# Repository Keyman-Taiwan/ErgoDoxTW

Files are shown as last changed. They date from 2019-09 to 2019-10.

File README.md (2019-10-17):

# ErgoDoxTW
Change was made based on [ErgoDone v1.5](https://github.com/ktec-hq/ErgoDone/commit/091d1d12327a9dc95b3b4be09c8e6d85ce0d4d30)  

## PCB Preview in KiCad
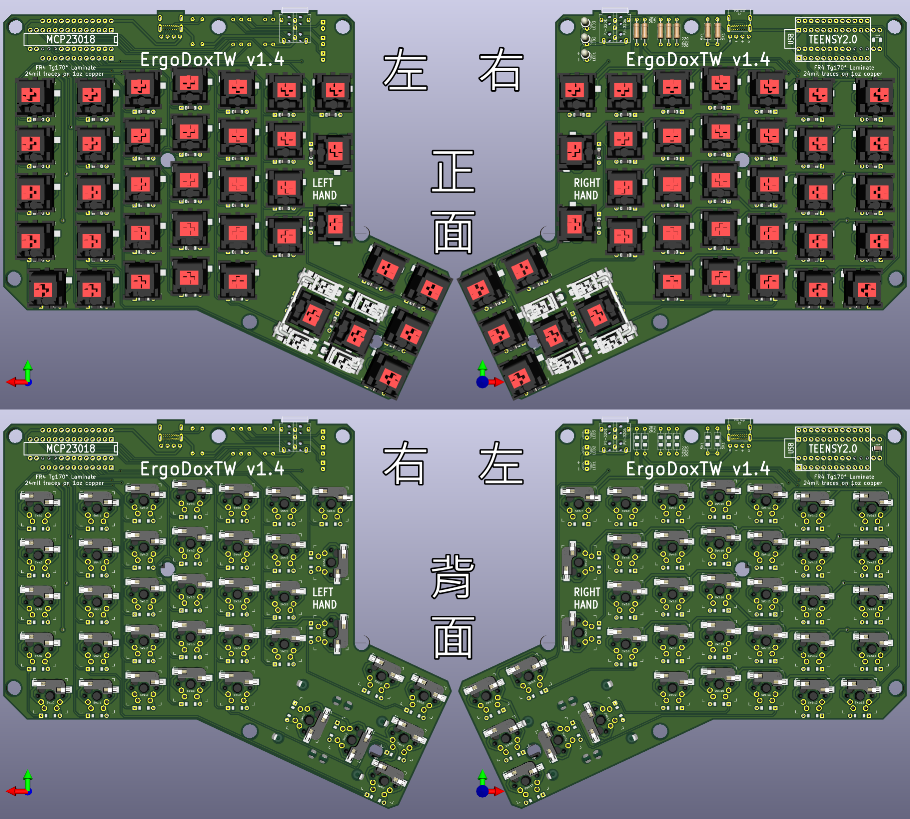
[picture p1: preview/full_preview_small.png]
pcb preview

You can find a larger image in the preview folder.

`IMPORTANT`: v1.4 has been validated.

## Difference/Improvement with ErgoDone
1. Rollback to use Teensy 2.0 for main controller (same as ErgoDox)
2. Rollback to use MCP23018 for IO expander (same as ErgoDox)
3. USB Type-C connector (only support USB 2.0 due to Teensy 2.0)
4. Support to use Kailh / Gateron hot plug socket
5. Support to use SMD 1206 component for Resistor and Capacitor
6. Change TRRS socket to PJ-320A and PJ-320E, which is more easy to find and cheapper. (please check folder ref_data/3.5mm
)
7. **`ONLY`** support 76 keys due to component change and pcb layout change.

## Branch Description
* master & USB_C_DIP_RightHand: Teensy IC on Right hand (Compatible with ErgoDox-EZ Configurator)
* USB_C_DIP: Teensy IC on Left hand

## Software Requirement
* Kicad 5.1.4

## KiCad library used by ErgoDoxTW
* [ai03-2725/Type-C Connecter](https://github.com/ai03-2725/Type-C.pretty): HRO-TYPE-C-31-M-12
* [daprice/keyswitches](https://github.com/daprice/keyswitches.pretty): Kailh hotplug socket
* Some components in ErgoDone's library
* Some components in ErgoDox's library

## KiCad Plugin used by ErgoDoxTW
* [NilujePerchut/kicad_scripts](https://github.com/NilujePerchut/kicad_scripts): teardrop pluging

## 3D model for preview
* [Kailh Hotplug Socket](https://github.com/qmk/qmk_hardware/tree/master/components): from qmk @ github
* [Cherry MX switch](https://github.com/ConstantinoSchillebeeckx/cherry-mx-switch): from ConstantinoSchillebeeckx @ github
* [Cherry MX Stabilizer](https://grabcad.com/library/cherry-mx-stabilizer-mx-1): from GrabCad
* SMD Diode / Resistor / LED are built-in model in KiCad

## BOM List
| Item | Amount | Comment |
|:---:|:---:|:---:|
| PCB boards | 2 | One for each hand |
| Teensy 2.0 | 1 | Maion controller |
| MCP23018 | 1 | I/O expander, Please choose DIP type |
| 2.54mm Header Pins | 24 | Unless pre-installed on the teensy board |
| Key switches | 76 | Compatible with Cherry MX is fine. |
| Key Switch Hotplug Socket | 76 | Kailh or Gateron. This is Optional |
| Key Caps | 76 | |
| 1N4148 diodes | 76 | SOD-123 package (SMD Type) or DO-35 (0.3” pitch) (Through-Hole Type) |
| 3mm T1 LED | 3 | |
| 220 Ω Resistor | 3 | Through-Hole Type Or 1206 SMD type (Red, Red, Brown) |
| 2.2k Ω Resistor | 2 | Through-Hole Type Or 1206 SMD type (Red, Red, Red) |
| 5.1k Ω Resistor | 2 | Through-Hole Type Or 1206 SMD type (Green, Brown, Red) |
| 0.1μ F Capacitor | 1 | ceramic capacitor (marked “104” for 10*104 picofarad, or 100nF), also supported 1206 smd type. Not strictly necessary but suggested. |
| USB Type C connector | 1 | 林躍電子 UB228-F16S4BR-A_DIP Or 浙富電子 16P 雙排 DIP |
| USB mini B plug with short cable | 1 | Such as H2955. Use for connect type c connector and teensy board |
| USB Type C Cable | 1 | A male to male cable, for connect keyboard to PC. (A to C) or (C to C) depend on your device. |
| 3.5mm TRRS socket | 2 | PJ-320A or PJ-320E |
| 3.5mm TRRS Cable | 1 | A male to male cable, for connect two pcbs. |
| ErgoDoxTW Keyboard case | 1 | Acrylic Case |

# Lisence
GPL v3

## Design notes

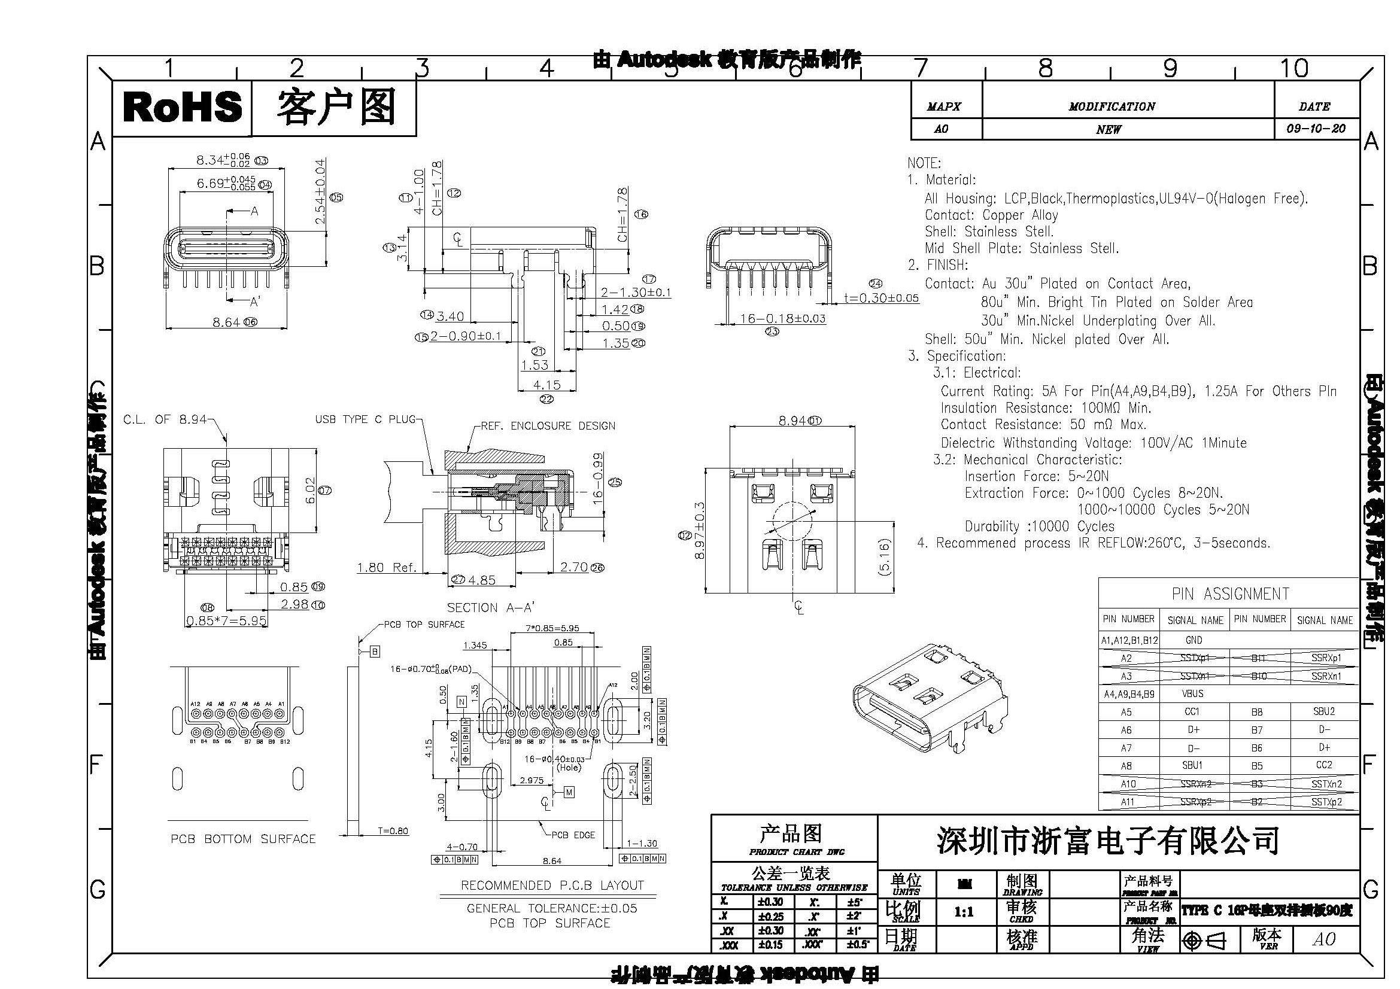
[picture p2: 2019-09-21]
ref_data/type_c/浙富电子_16P_雙排_DIP.jpg

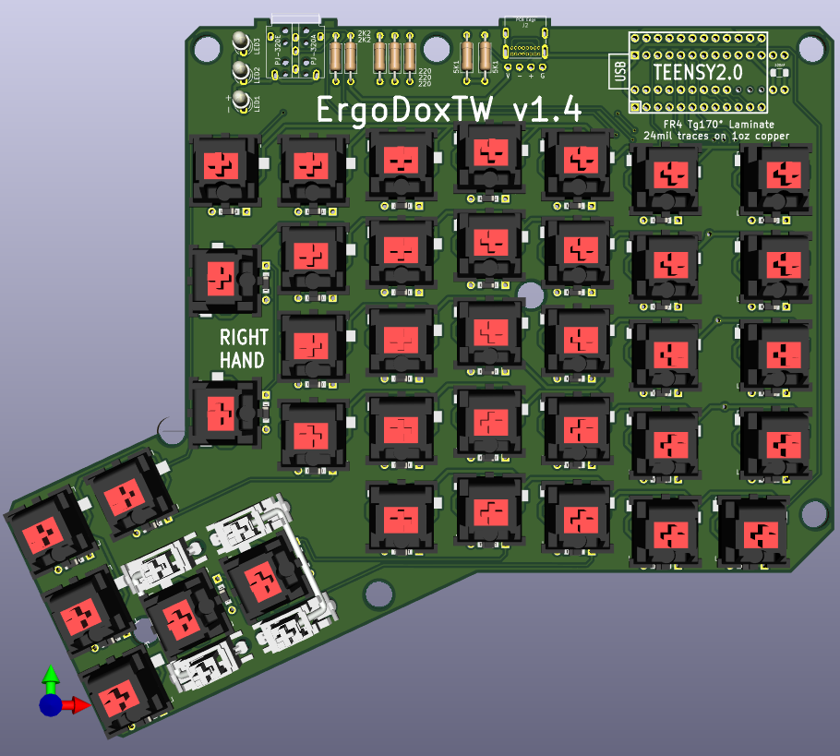
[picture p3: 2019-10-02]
preview/v1.4_RightHand_Top.png

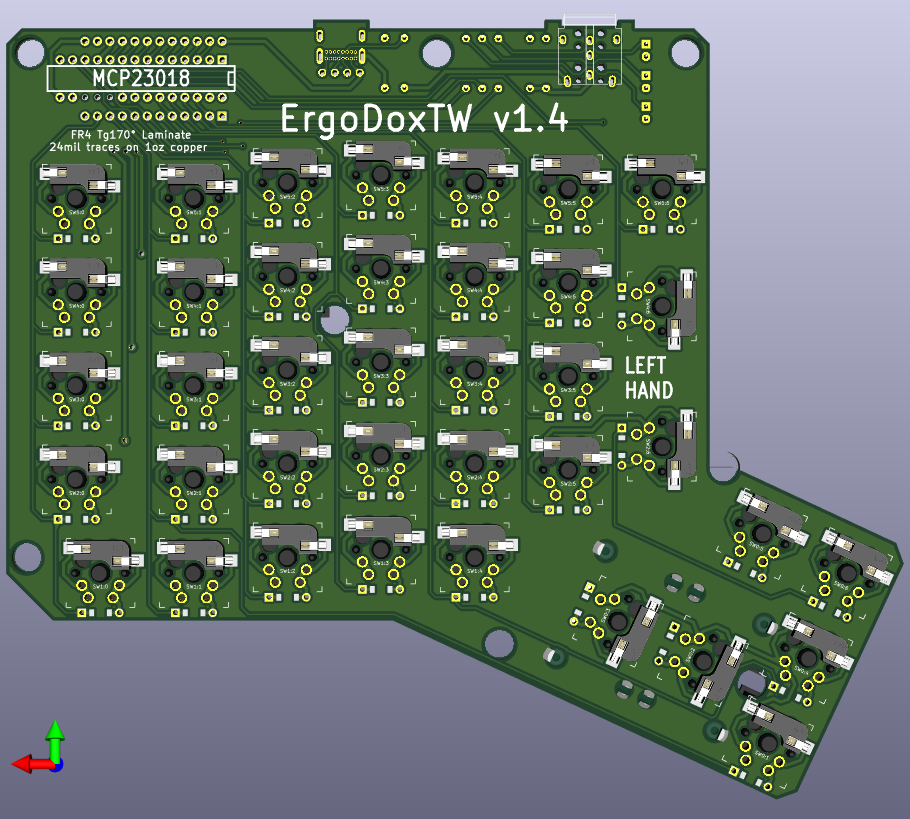
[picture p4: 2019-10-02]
preview/v1.4_RightHand_Bottom.png

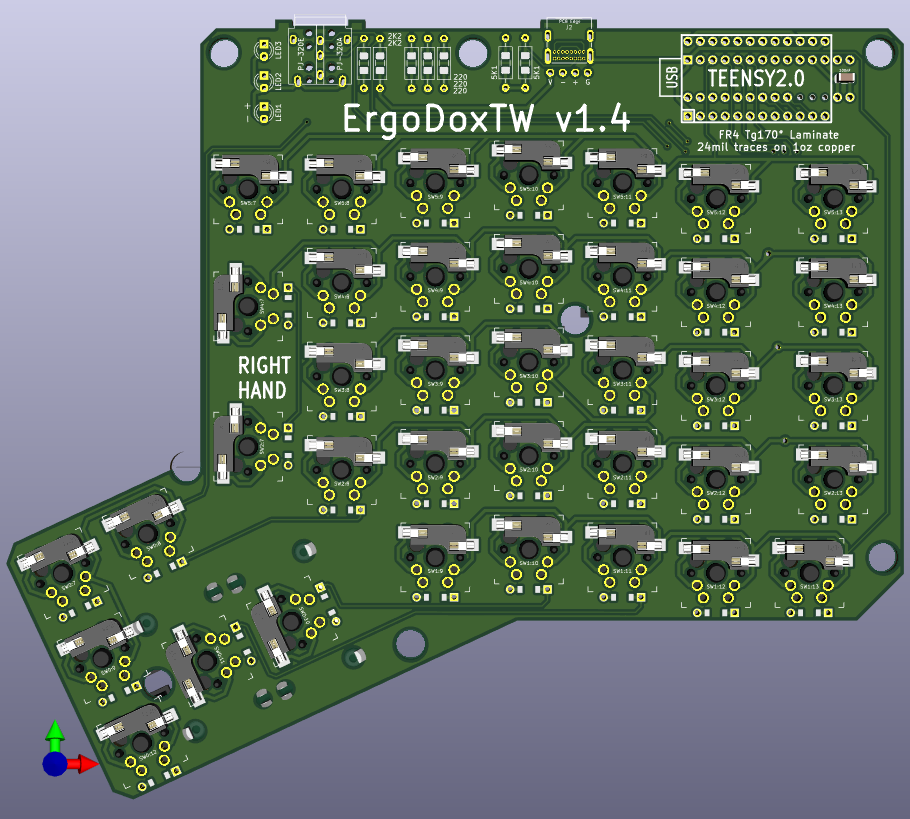
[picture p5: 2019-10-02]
preview/v1.4_LeftHand_Bottom.png

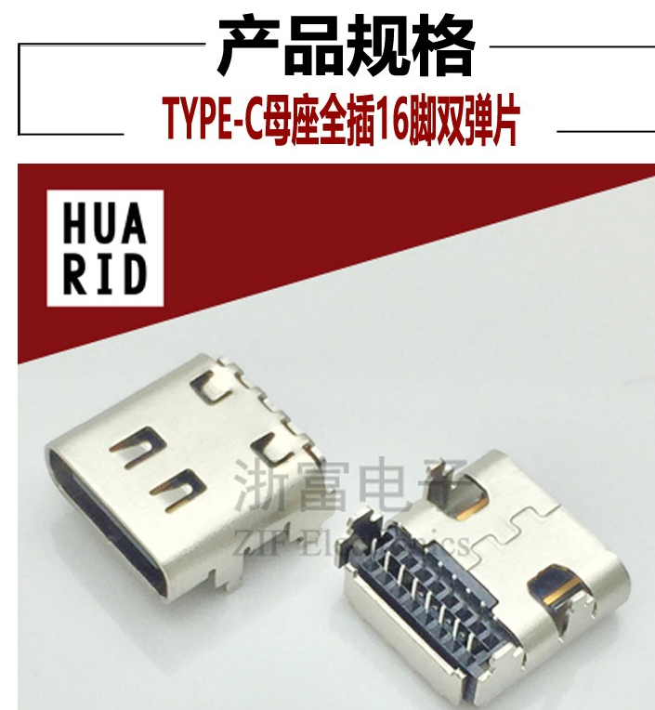
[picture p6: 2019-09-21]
ref_data/type_c/浙富电子_16P_雙排_DIP.png

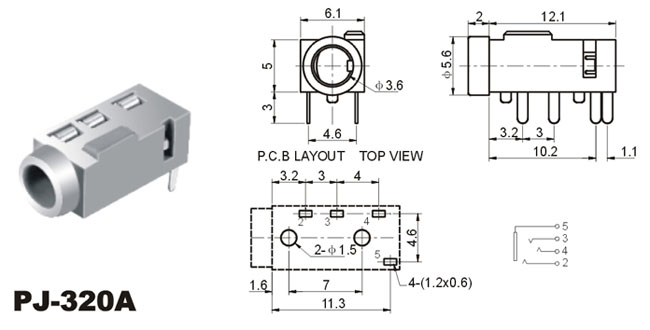
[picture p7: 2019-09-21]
ref_data/3.5mm/PJ-320A_4p.jpg

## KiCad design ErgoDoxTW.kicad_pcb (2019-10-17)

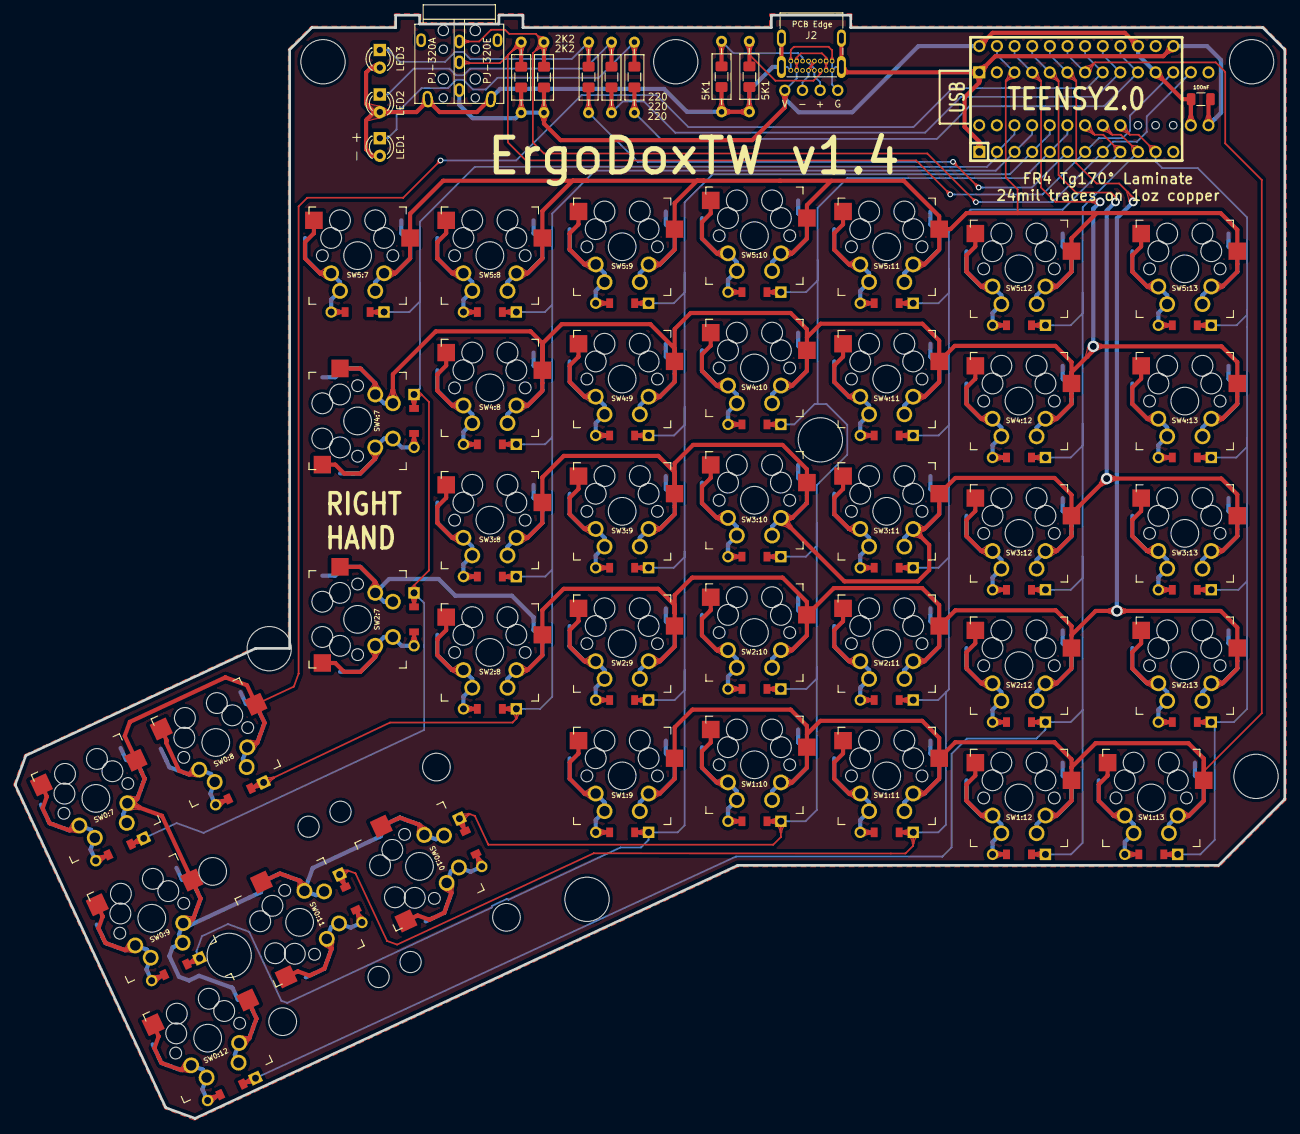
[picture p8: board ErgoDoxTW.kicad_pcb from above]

Board: 2 copper layers, 182.8 x 158.9 mm, 63 parts (1 on the bottom side), 65 nets.

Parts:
100nF: 100nF; C_1206_3216Metric
J1: 3.5mm; PJ-320A_and_320E-Dual
J2: USB_C; TYPE_C_UB228-F16S4BR-A_DIP
LED1: LEDa; LED_D3.0mm_Clear
LED2: LEDb; LED_D3.0mm_Clear
LED3: LEDc; LED_D3.0mm_Clear
R1, R2: 2K2; R_Axial_DIN0207_L6.3mm_D2.5mm_P10.16mm_Horizontal
R3, R6: 2K2; R_1206_3216Metric_Pad1.42x1.75mm_HandSolder
R4, R5: 5K1; R_Axial_DIN0207_L6.3mm_D2.5mm_P10.16mm_Horizontal
R7, R8: 5K1; R_1206_3216Metric_Pad1.42x1.75mm_HandSolder
RA1: LEDa; R_Axial_DIN0207_L6.3mm_D2.5mm_P10.16mm_Horizontal
RA2: 220; R_1206_3216Metric_Pad1.42x1.75mm_HandSolder
RB1: LEDb; R_Axial_DIN0207_L6.3mm_D2.5mm_P10.16mm_Horizontal
RB2: 220; R_1206_3216Metric_Pad1.42x1.75mm_HandSolder
RC1: LEDc; R_Axial_DIN0207_L6.3mm_D2.5mm_P10.16mm_Horizontal
RC2: 220; R_1206_3216Metric_Pad1.42x1.75mm_HandSolder
S1, S2: STAB200; STAB_PCB940
S3: MEHCINAL; ErgoDOXmech
SW0:7: SW0:6; Kailh_socket_diode_smd
SW0:8: SW0:5; Kailh_socket_diode_smd
SW0:9: SW0:4; Kailh_socket_diode_smd
SW0:10: SW0:3; Kailh_socket_diode_smd
SW0:11: SW0:2; Kailh_socket_diode_smd
SW0:12: SW0:1; Kailh_socket_diode_smd
SW1:9: SW1:4; Kailh_socket_diode_smd
SW1:10: SW1:3; Kailh_socket_diode_smd
SW1:11: SW1:2; Kailh_socket_diode_smd
SW1:12: SW1:1; Kailh_socket_diode_smd
SW1:13: SW1:0; Kailh_socket_diode_smd
SW2:7: SW2:6; Kailh_socket_diode_smd
SW2:8: SW2:5; Kailh_socket_diode_smd
SW2:9: SW2:4; Kailh_socket_diode_smd
SW2:10: SW2:3; Kailh_socket_diode_smd
SW2:11: SW2:2; Kailh_socket_diode_smd
SW2:12: SW2:1; Kailh_socket_diode_smd
SW2:13: SW2:0; Kailh_socket_diode_smd
SW3:8: SW3:5; Kailh_socket_diode_smd
SW3:9: SW3:4; Kailh_socket_diode_smd
SW3:10: SW3:3; Kailh_socket_diode_smd
SW3:11: SW3:2; Kailh_socket_diode_smd
SW3:12: SW3:1; Kailh_socket_diode_smd
SW3:13: SW3:0; Kailh_socket_diode_smd
SW4:7: SW4:6; Kailh_socket_diode_smd
SW4:8: SW4:5; Kailh_socket_diode_smd
SW4:9: SW4:4; Kailh_socket_diode_smd
SW4:10: SW4:3; Kailh_socket_diode_smd
SW4:11: SW4:2; Kailh_socket_diode_smd
SW4:12: SW4:1; Kailh_socket_diode_smd
SW4:13: SW4:0; Kailh_socket_diode_smd
SW5:7: SW5:6; Kailh_socket_diode_smd
SW5:8: SW5:5; Kailh_socket_diode_smd
SW5:9: SW5:4; Kailh_socket_diode_smd
SW5:10: SW5:3; Kailh_socket_diode_smd
SW5:11: SW5:2; Kailh_socket_diode_smd
SW5:12: SW5:1; Kailh_socket_diode_smd
SW5:13: SW5:0; Kailh_socket_diode_smd
U2: MCP23018; DIP28_300
U4: TEENSY2.0; TEENSY_2.0_WO_RESET

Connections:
/COL0: SW1:13.4, SW2:13.4, SW3:13.4, SW4:13.4, SW5:13.4, U2.20, U4.11
/COL1: SW0:12.4, SW1:12.4, SW2:12.4, SW3:12.4, SW4:12.4, SW5:12.4, U2.21, U4.10
/COL4: SW0:9.4, SW1:9.4, SW2:9.4, SW3:9.4, SW4:9.4, SW5:9.4, U2.24, U4.4
/COL5: SW0:8.4, SW2:8.4, SW3:8.4, SW4:8.4, SW5:8.4, U2.25, U4.3
/COL6: SW0:7.4, SW2:7.4, SW4:7.4, SW5:7.4, U2.26, U4.2
/COL10: SW0:10.4, SW1:10.4, SW2:10.4, SW3:10.4, SW4:10.4, SW5:10.4, U2.23, U4.5
/COL11: SW0:11.4, SW1:11.4, SW2:11.4, SW3:11.4, SW4:11.4, SW5:11.4, U2.22, U4.9
/LED_A: RA1.1, RA2.1, U2.10, U4.21
/LED_B: RB1.1, RB2.1, U2.9, U4.22
/LED_C: RC1.1, RC2.1, U4.6
/ROW0: SW0:7.1, SW0:8.1, SW0:9.1, SW0:10.1, SW0:11.1, SW0:12.1, U2.8, U4.23
/ROW1: SW1:9.1, SW1:10.1, SW1:11.1, SW1:12.1, SW1:13.1, U2.7, U4.24
/ROW2: SW2:7.1, SW2:8.1, SW2:9.1, SW2:10.1, SW2:11.1, SW2:12.1, SW2:13.1, U2.6, U4.25
/ROW3: SW3:8.1, SW3:9.1, SW3:10.1, SW3:11.1, SW3:12.1, SW3:13.1, U2.5, U4.26
/ROW4: SW4:7.1, SW4:8.1, SW4:9.1, SW4:10.1, SW4:11.1, SW4:12.1, SW4:13.1, U2.4, U4.27
/ROW5: SW5:7.1, SW5:8.1, SW5:9.1, SW5:10.1, SW5:11.1, SW5:12.1, SW5:13.1, U2.3, U4.28
/SCLM: J1.3, R2.2, R6.2, U2.12, U4.7
/SDAM: J1.2, R1.2, R3.2, U2.13, U4.8
GND: 100nF.2, J1.5, J2.A1, J2.A12, J2.B1, J2.B12, J2.S1, LED1.2, LED2.2, LED3.2, R4.2, R5.2, R7.2, R8.2, U2.1, U2.15, U4.1, U4.18
unnamed: J2.A5, R5.1, R7.1
unnamed: J2.A6, J2.B6
unnamed: J2.A7, J2.B7
unnamed: J2.B5, R4.1, R8.1
unnamed: LED1.1, RA1.2, RA2.2
unnamed: LED2.1, RB1.2, RB2.2
unnamed: LED3.1, RC1.2, RC2.2
unnamed: SW0:7.2, SW0:7.3
unnamed: SW0:8.2, SW0:8.3
unnamed: SW0:9.2, SW0:9.3
unnamed: SW0:10.2, SW0:10.3
unnamed: SW0:11.2, SW0:11.3
unnamed: SW0:12.2, SW0:12.3
unnamed: SW1:9.2, SW1:9.3
unnamed: SW1:10.2, SW1:10.3
unnamed: SW1:11.2, SW1:11.3
unnamed: SW1:12.2, SW1:12.3
unnamed: SW1:13.2, SW1:13.3
unnamed: SW2:7.2, SW2:7.3
unnamed: SW2:8.2, SW2:8.3
unnamed: SW2:9.2, SW2:9.3
unnamed: SW2:10.2, SW2:10.3
unnamed: SW2:11.2, SW2:11.3
unnamed: SW2:12.2, SW2:12.3
unnamed: SW2:13.2, SW2:13.3
unnamed: SW3:8.2, SW3:8.3
unnamed: SW3:9.2, SW3:9.3
unnamed: SW3:10.2, SW3:10.3
unnamed: SW3:11.2, SW3:11.3
unnamed: SW3:12.2, SW3:12.3
unnamed: SW3:13.2, SW3:13.3
unnamed: SW4:7.2, SW4:7.3
unnamed: SW4:8.2, SW4:8.3
unnamed: SW4:9.2, SW4:9.3
unnamed: SW4:10.2, SW4:10.3
unnamed: SW4:11.2, SW4:11.3
unnamed: SW4:12.2, SW4:12.3
unnamed: SW4:13.2, SW4:13.3
unnamed: SW5:7.2, SW5:7.3
unnamed: SW5:8.2, SW5:8.3
unnamed: SW5:9.2, SW5:9.3
unnamed: SW5:10.2, SW5:10.3
unnamed: SW5:11.2, SW5:11.3
unnamed: SW5:12.2, SW5:12.3
unnamed: SW5:13.2, SW5:13.3
VCC: 100nF.1, J1.4, J2.A4, J2.A9, J2.B4, J2.B9, R1.1, R2.1, R3.1, R6.1, U2.11, U2.16, U4.20, U4.29

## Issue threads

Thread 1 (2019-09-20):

KiCAD diff chart

jamessa, 2019-09-20:
I want a diff chart between major release

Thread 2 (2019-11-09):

Consolidate case and PCB into one repository.

jamessa, 2019-11-09:
Suggest a structure like like and make 1.4 release tag.

```
ErgoDox
├── PrintedCircuitBoard
├── AcrylicCase
└── README.md
```

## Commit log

2019-09-12 update v1.0
    1. Change USB VCC trace to 0.609 mm
    2. Make all via larger
    3. reroute the trace in thumb area
    4. add some pcb text
    5. update README.md
    [ErgoDoxTW-B_Mask.gbr, ErgoDoxTW-B_Paste.gbr, ErgoDoxTW-B_SilkS.gbr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]
2019-09-12 Add pcb preview image to README.md
2019-09-17 update to v1.2
    1. change 3.5mm audio socket component to PJ-320A (pin on right side)
    and PJ-320L (pin on left side)
    2. change key switch layout
    3. change
    trace to 0.609 mm for key switch (due to above)
    4. fix some typo
    [ErgoDoxTW-B_Mask.gbr, ErgoDoxTW-B_Paste.gbr, ErgoDoxTW-B_SilkS.gbr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]
2019-09-18 update v1.2.1
    Main change :
    1. fix 3.5mm audio jack position
    Minor change:
    1. add key_switch / stabilizer 3d models for preview
    2. add full pcb preview image
    [ErgoDoxTW.kicad_pcb]
2019-09-19 update v1.3
    support PJ-320E 3.5mm audio jack
    [ErgoDoxTW.kicad_pcb, ErgoDoxTW.sch]
2019-09-30 update v1.4 from branch USB_C_DIP_RightHand
    1. rename project to ErgoDoxTW
    2. Drill hole is compatible with ErgoDox
    3. fix silk print on PJ-320A_and_PJ-320E kicad module
    4. remove 3d models preview for unused components
    5. remove unused components and 3d models step files
    [ErgoDoneTW.kicad_pcb, ErgoDoxTW.kicad_pcb, ErgoDoxTW.sch]
2019-10-17 v1.4 formal release
    update TRRS position and silksprint
    [ErgoDoxTW-B_Mask.gbr, ErgoDoxTW-B_Paste.gbr, ErgoDoxTW-B_SilkS.gbr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]
